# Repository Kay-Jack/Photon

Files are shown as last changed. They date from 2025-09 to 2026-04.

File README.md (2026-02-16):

# Photon

## Description
The goal of this project was to create a simple but powerful bike LED light using my remaining 18650 batteries. This is not a weak light, it delivers strong output and can be made even more powerful by swapping two resistors (one per LED) on the current contorl ICs.

A major motivation for this project was to lower the cost of bike lights, as high-quality options are often overpriced for what they offer. I also aimed to reduce labor and assembly costs, since most units would be hand-soldered. This was done by minimizing the number of unique components on the board.

The repository includes the full schematic, PCB layout, manufacturing files, and firmware for the Photon V5 revision, currently working on V6.

## Complete
- Schematic
- Board Design 
- Testing and Validation

## WIP
- Enclosure 
- New STM32 firmware 

## Features
- **Power-Efficient Design**: Utilizes a buck converter and low-power STM32
- **Compact Size**: the board compact roughly the same size as an 18650. 
- **LED Illumination**: 3W High-brightness LEDs with current control ICs.
- **Integrated Battery Charging**: A TP4056 is used for battery charging with a bidirectional side mounted LED for indication
- **Battery Protections**: Undervoltage, overvoltage and short protection is included on the board
- **Charge Detection**: The board will automatically shut off the power to the system if it detects that the board has been plugged in for charging. 
- **Debug Header**: The board uses staggered 2.54 mm header pins that create a spring effect, allowing solderless use similar to a debug header.

## Images
### PCB Front View
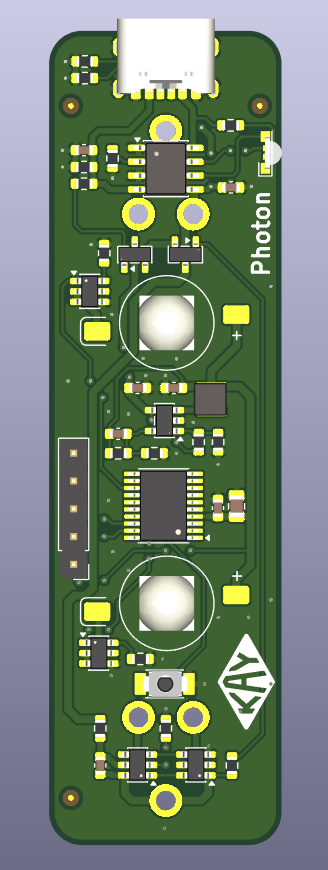
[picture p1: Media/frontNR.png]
PCB Front


### PCB Back View
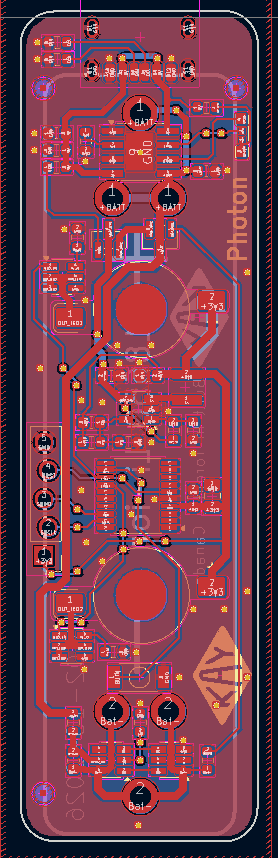
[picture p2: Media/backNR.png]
PCB Back


### Schematic 
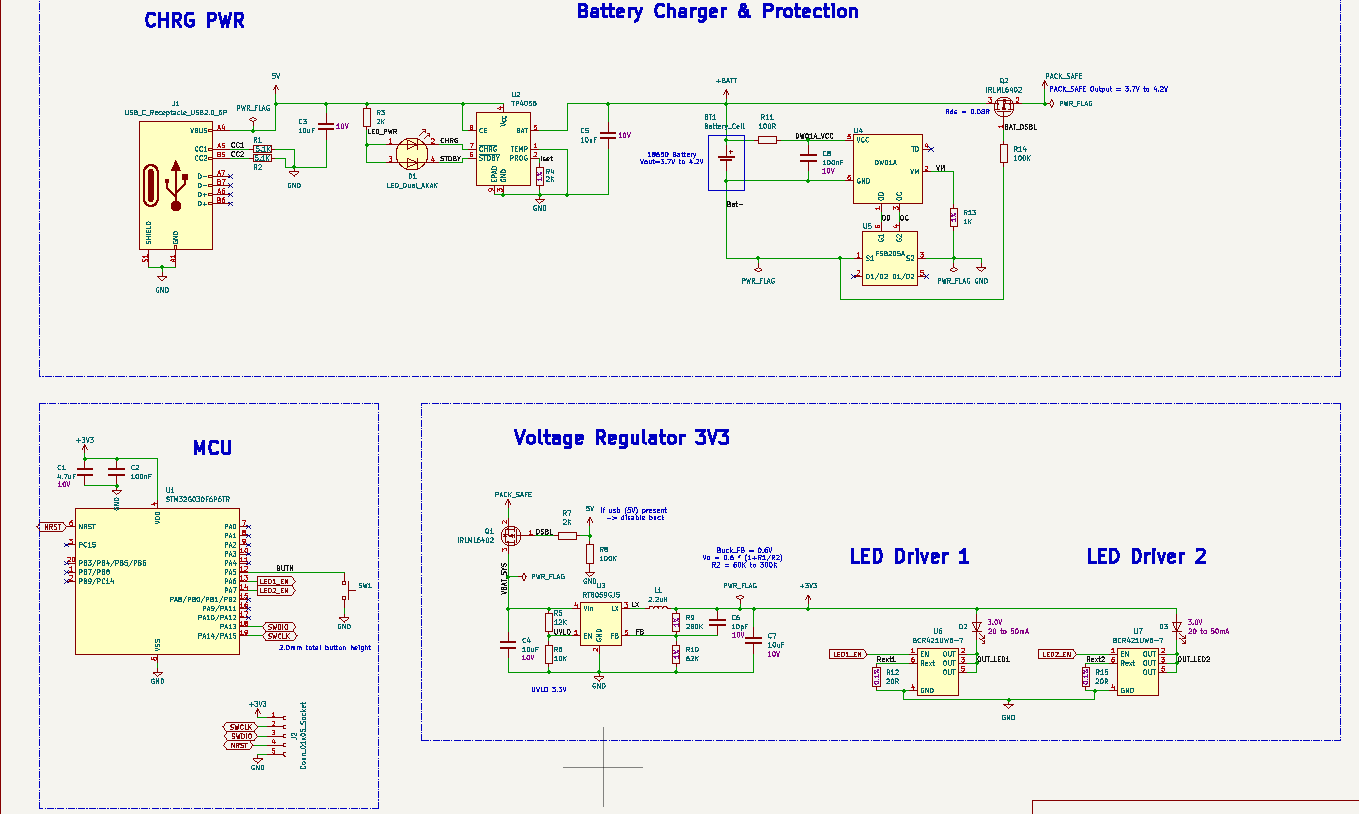
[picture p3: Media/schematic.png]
Schematic


## Version
This is version V6 of the Photon project.

## Repository
Hosted on GitHub: [AirMatress/Photon](https://github.com/AirMatress/Photon)

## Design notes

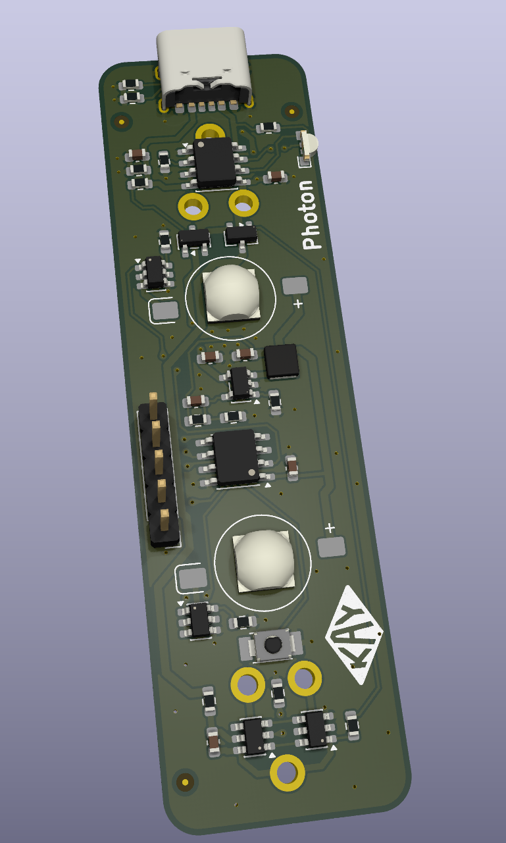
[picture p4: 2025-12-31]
Media/front.png

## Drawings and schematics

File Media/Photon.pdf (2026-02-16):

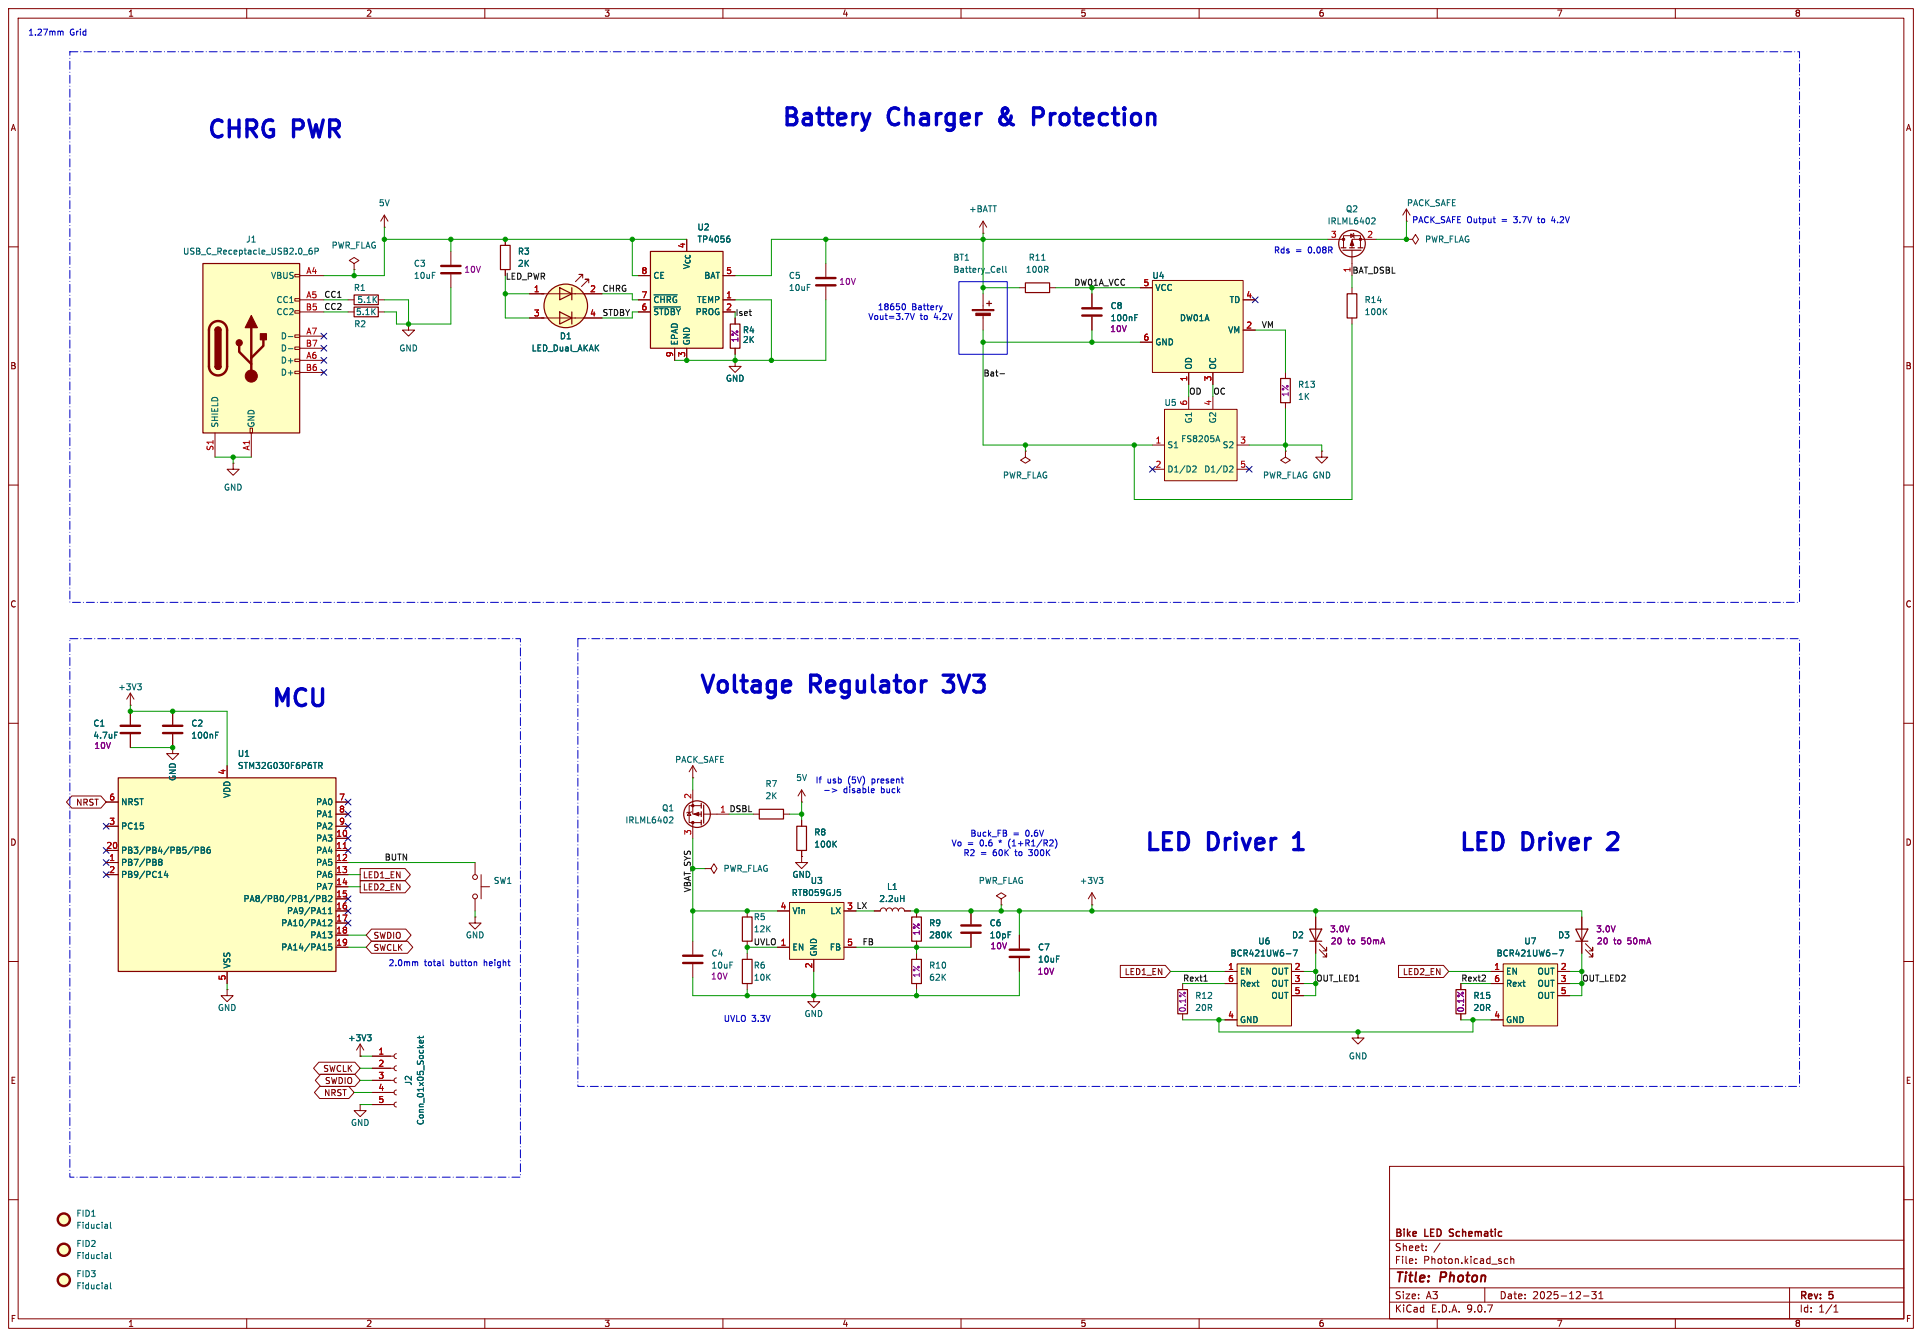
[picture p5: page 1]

Battery Charger & Protection
PACK_SAFE Output = 3.7V to 4.2V LED Driver 2

Vo = 0.6 * (1+R1/R2) R2 = 60K to 300K Voltage Regulator 3V3

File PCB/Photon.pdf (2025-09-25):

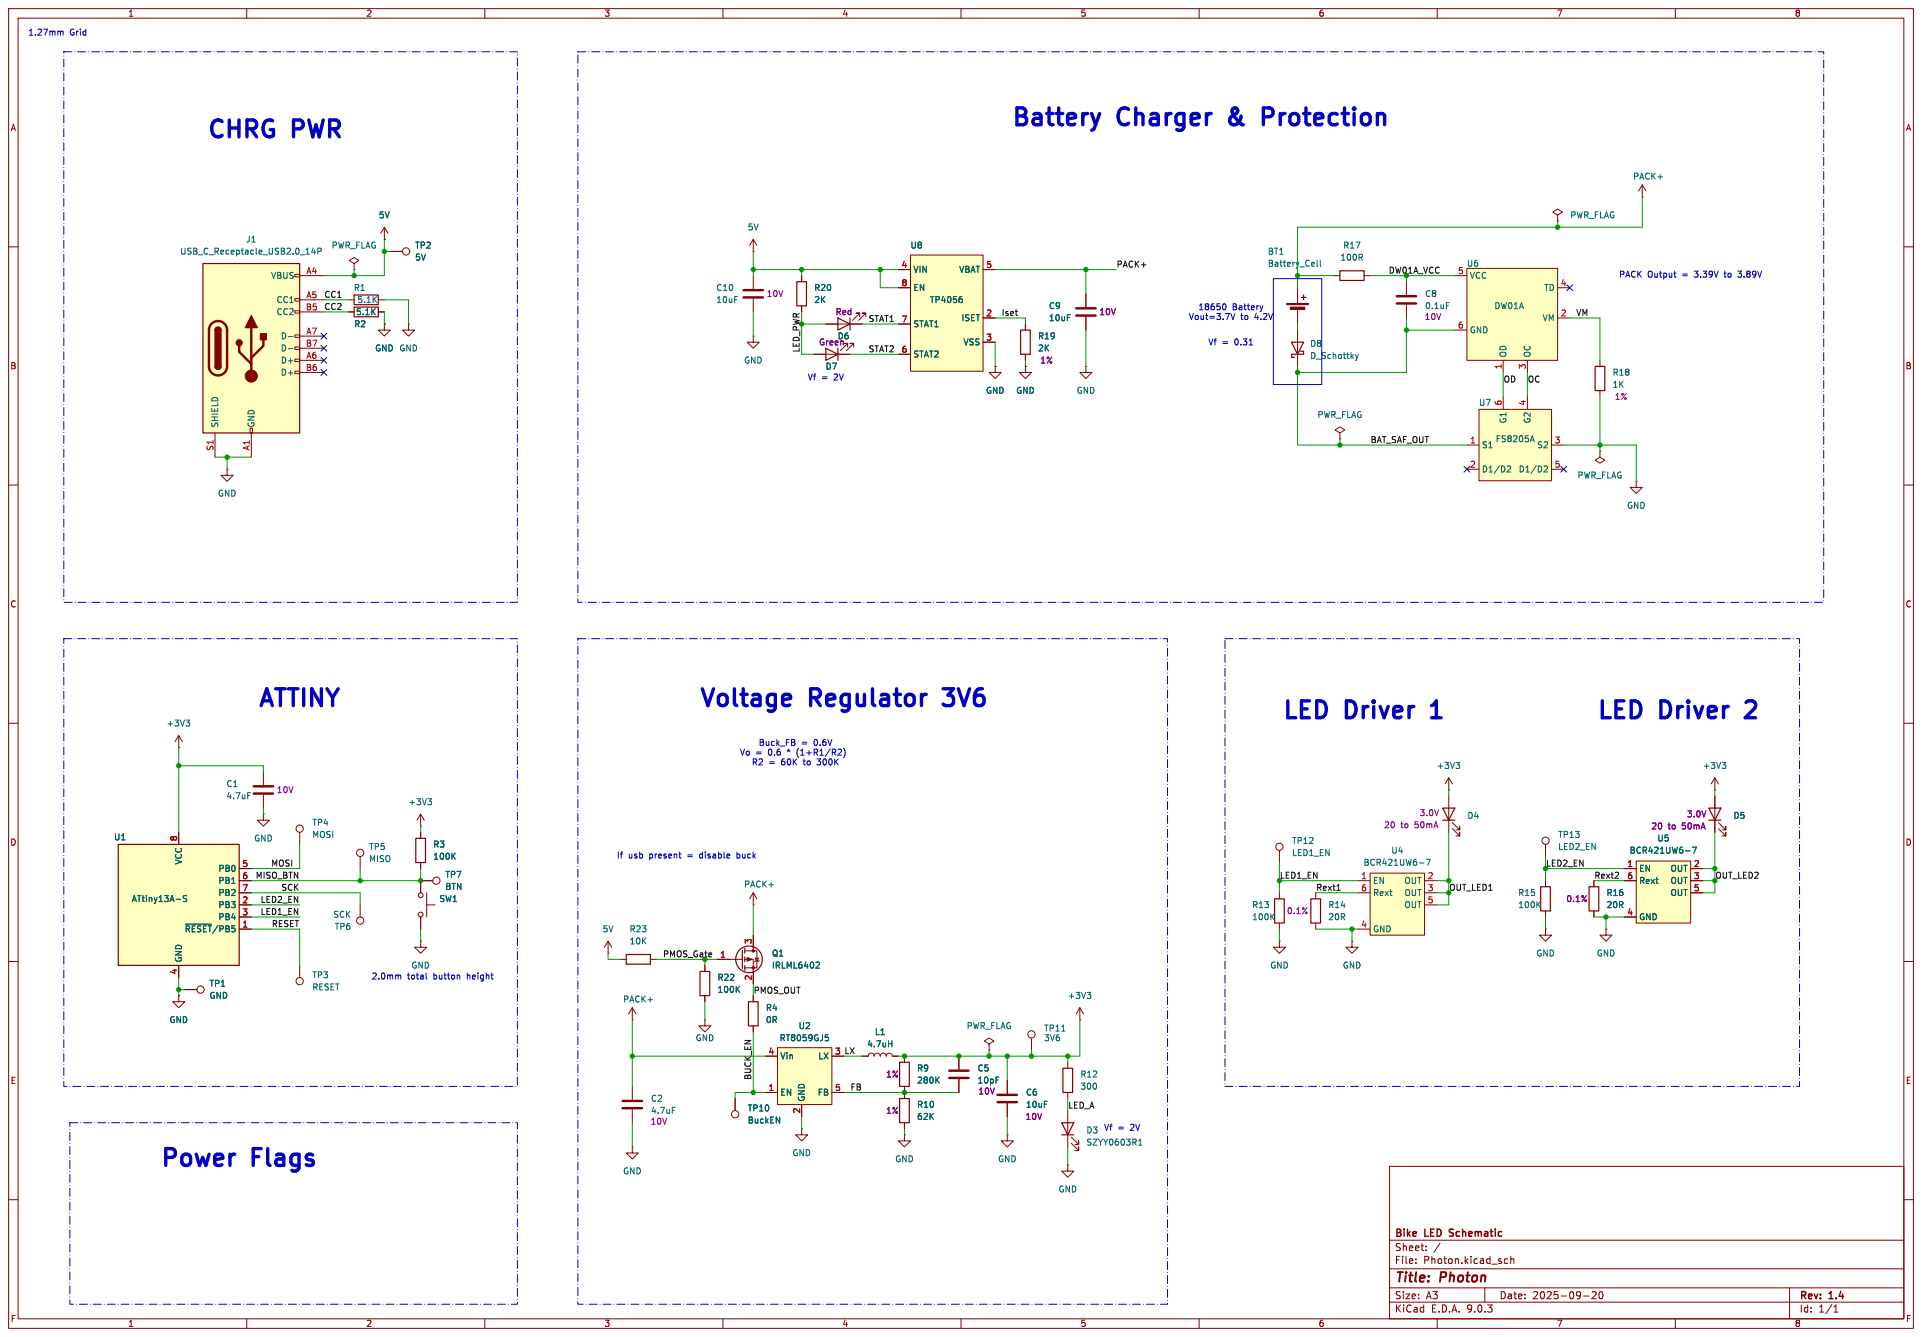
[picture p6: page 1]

If usb present = disable buck

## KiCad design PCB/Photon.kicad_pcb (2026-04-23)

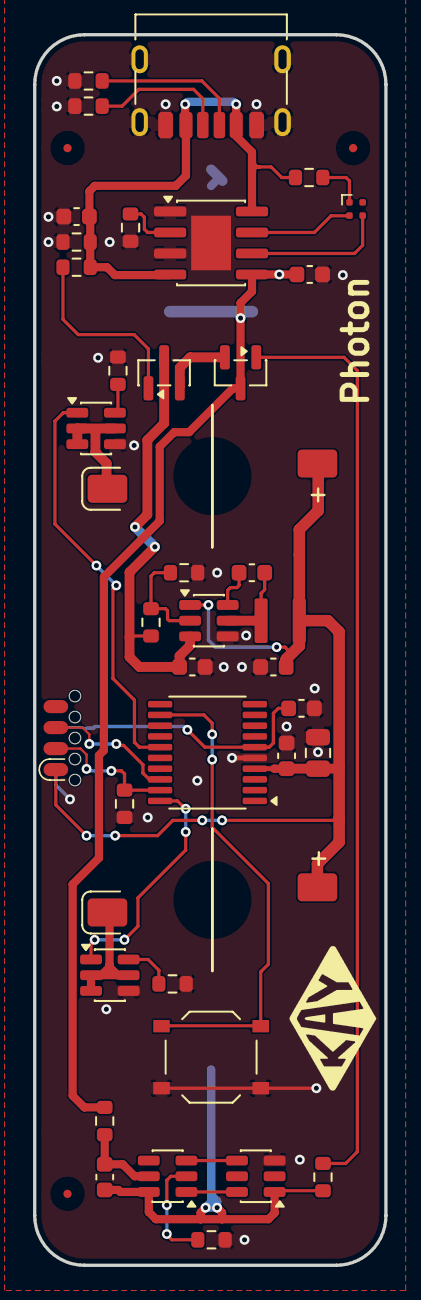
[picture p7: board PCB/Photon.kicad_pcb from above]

Board: 2 copper layers, 21.2 x 74.4 mm, 43 parts (1 on the bottom side), 32 nets.

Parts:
BT1: Battery_Cell; 18650 Tin Strips
C1: 4.7uF; C_0805_2012Metric
C2, C6, C8, C10: 100nF; C_0603_1608Metric
C3, C4, C5: 10uF; C_0603_1608Metric
C9: 22uF; C_0603_1608Metric
D1: XL-1010RGB-YG; LED_Wurth_150044M155260
D2, D3: LED; 3W LED 9mm
FID1, FID2, FID3: Fiducial; Fiducial_0.5mm_Mask1.5mm
J1: USB_C_Receptacle_USB2.0_6P; USB_C_Receptacle_HRO_TYPE-C-31-M-17
J2: SOIC 8 Debug Clip; SOIC_clipProgSmall
L1: 4.7uH; SMD 3x3mm Power Inductor
Q1, Q2: IRLML6402; SOT-23
R1, R2: 5.1K; R_0603_1608Metric
R3, R4, R7: 2K; R_0603_1608Metric
R5: 180K; R_0603_1608Metric
R6, R8, R14: 100K; R_0603_1608Metric
R9: 10K; R_0603_1608Metric
R11: 100R; R_0603_1608Metric
R12, R15: 20R; R_0603_1608Metric
R13: 1K; R_0603_1608Metric
SW1: TS-1088-AR02016; SW_Push_1P1T_XKB_TS-1187A
U1: STM32G030F6P6TR; TSSOP-20_4.4x6.5mm_P0.65mm
U2: TP4056; SOIC-8-1EP_3.9x4.9mm_P1.27mm_EP2.41x3.3mm
U3: AP63203WU; TSOT-23-6
U4: DW01A; SOT-23-6
U5: FS8205A; SOT-23-6
U6, U7: BCR421UW6-7; SOT-23-6

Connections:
5V: C3.2, J1.A9 (VBUS), J1.B9 (VBUS), R3.1, R7.2, R8.1, U2.4 (V_{CC}), U2.8 (CE)
+3V3: C1.2, C2.1, C9.2, D2.2 (A), D3.2 (A), J2.1, L1.2, U1.4 (VDD), U3.1 (FB)
+BATT: BT1.1 (+), C5.2, Q2.3 (D), R11.1, U2.5 (BAT)
/BAT_DSBL: Q2.1 (G), R14.2
/BST: C6.2, U3.6 (BST)
/BUTN: SW1.1, U1.12 (PA5)
/Bat-: BT1.2 (-), C8.1, R14.1, U4.6 (GND), U5.1 (S1)
/CC1: J1.A5 (CC1), R1.1
/CC2: J1.B5 (CC2), R2.1
/CHRG: D1.3 (RK), U2.7 (~CHRG)
/DSBL: Q1.1 (G), R7.1
/DW01A_VCC: C8.2, R11.2, U4.5 (VCC)
/Iset: R4.1, U2.2 (PROG)
/LED_PWR: D1.1 (A), R3.2
/OC: U4.3 (OC), U5.4 (G2)
/OD: U4.1 (OD), U5.6 (G1)
/OUT_LED1: D2.1 (K), U6.2 (OUT), U6.3 (OUT), U6.5 (OUT)
/OUT_LED2: D3.1 (K), U7.2 (OUT), U7.3 (OUT), U7.5 (OUT)
/Rext1: R12.1, U6.6 (Rext)
/Rext2: R15.1, U7.6 (Rext)
/STDBY: D1.4 (GK), U2.6 (~STDBY)
/SW: C6.1, L1.1, U3.5 (SW)
/UVLO: R5.2, R6.1, U3.2 (EN)
/VBAT_SYS: C4.2, Q1.3 (D), R5.1, U3.3 (IN)
/VM: R13.2, U4.2 (VM)
GND: C1.1, C2.2, C3.1, C4.1, C5.1, C9.1, C10.1, J1.A12 (GND), J1.B12 (GND), J1.S1 (SHIELD), J2.8, R1.2, R2.2, R4.2, R6.2, R8.2, R9.2, R12.2, R13.1, R15.2, SW1.2, U1.5 (VSS), U2.1 (TEMP), U2.3 (GND), U2.9 (EPAD), U3.4 (GND), U5.3 (S2), U6.4 (GND), U7.4 (GND)
LED1_EN: U1.15 (PA8/PB0/PB1/PB2), U6.1 (EN)
LED2_EN: U1.20 (PB3/PB4/PB5/PB6), U7.1 (EN)
NRST: C10.2, J2.6, U1.6 (NRST)
PACK_SAFE: Q1.2 (S), Q2.2 (S)
SWCLK: J2.2, R9.1, U1.19 (PA14/PA15)
SWDIO: J2.3, U1.18 (PA13)

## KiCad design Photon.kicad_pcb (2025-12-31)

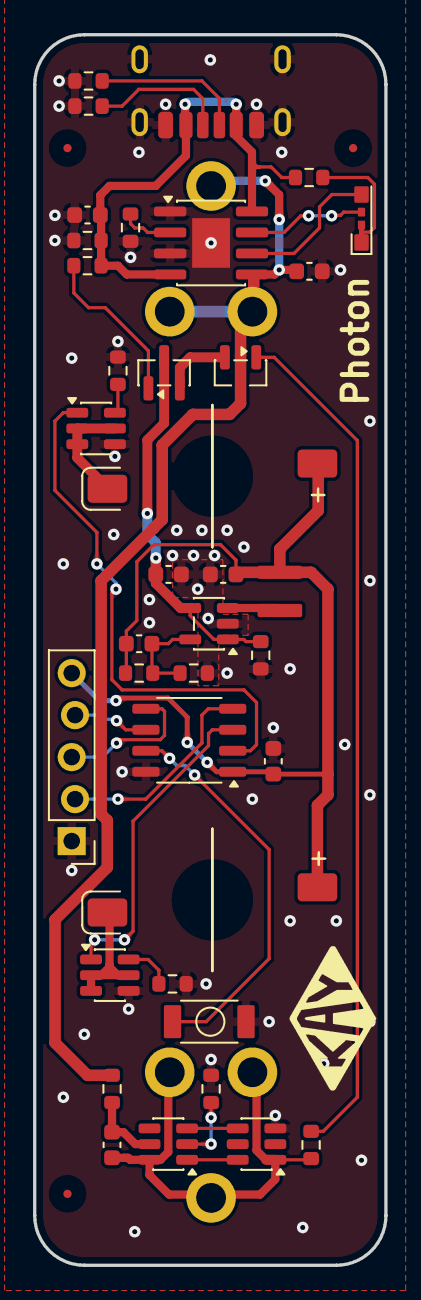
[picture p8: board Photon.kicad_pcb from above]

Board: 2 copper layers, 21.2 x 74.4 mm, 41 parts (1 on the bottom side), 31 nets.

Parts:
BT1: Battery_Cell; Spring Battery TH
C1, C7: 100nF; C_0603_1608Metric
C2, C3, C5, C6: 10uF; C_0603_1608Metric
C4: 10pF; C_0603_1608Metric
D1: LED_Dual_AKAK; 3.9mm Bi directional side mount LED
D2, D3: LED; 3W LED 9mm
FID1, FID2, FID3: Fiducial; Fiducial_0.5mm_Mask1.5mm
J1: USB_C_Receptacle_USB2.0_14P; USB_C_Receptacle_HRO_TYPE-C-31-M-17
J2: Conn_01x05_Socket; PinHeader_1x05_P2.54mm_Vertical
L1: 2.2uH; SMD 3x3mm Power Inductor
Q1, Q2: IRLML6402; SOT-23
R1, R2: 5.1K; R_0603_1608Metric
R4, R7, R10: 2K; R_0603_1608Metric
R5, R6, R19: 100K; R_0603_1608Metric
R8: 280K; R_0603_1608Metric
R9: 62K; R_0603_1608Metric
R13, R16: 20R; R_0603_1608Metric
R14: 100R; R_0603_1608Metric
R17: 1K; R_0603_1608Metric
SW1: TS-1088-AR02016; 5mm Push Button
U1: PY32F002AL15S6TU; SOP-8_3.9x4.9mm_P1.27mm
U2: TP4056; SOIC-8-1EP_3.9x4.9mm_P1.27mm_EP2.29x3mm
U3: RT8059GJ5; SOT-23-5
U4, U7: BCR421UW6-7; SOT-23-6
U5: DW01A; SOT-23-6
U6: FS8205A; SOT-23-6

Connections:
5V: C3.2, J1.A9 (VBUS), J1.B9 (VBUS), R4.2, R5.1, R7.1, U2.4 (V_{CC}), U2.8 (CE)
+3V3: C1.2, C4.2, C5.2, D2.2 (A), D3.2 (A), J2.5, L1.2, R8.1, U1.1 (VDD)
+BATT: BT1.1 (+), C6.2, Q2.3 (D), R14.1, U2.5 (BAT)
/BAT_DSBL: Q2.1 (G), R19.2
/BTN: SW1.1, U1.7 (PA1)
/Bat-: BT1.2 (-), C7.1, R19.1, U5.6 (GND), U6.1 (S1)
/CC1: J1.A5 (CC1), R1.1
/CC2: J1.B5 (CC2), R2.1
/CHRG: D1.2 (K1), U2.7 (~CHRG)
/DSBL: Q1.1 (G), R4.1
/DW01A_VCC: C7.2, R14.2, U5.5 (VCC)
/FB: C4.1, R8.2, R9.1, U3.5 (FB)
/Iset: R10.1, U2.2 (PROG)
/LED1_EN: U1.2 (PA4/PA10), U4.1 (EN)
/LED2_EN: U1.3 (PA3), U7.1 (EN)
/LED_PWR: D1.1 (A1), D1.3 (A2), R7.2
/LX: L1.1, U3.3 (LX)
/NRST: J2.4, U1.6 (PA2/PF2/NRST)
/OC: U5.3 (OC), U6.4 (G2)
/OD: U5.1 (OD), U6.6 (G1)
/OUT_LED1: D2.1 (K), U4.2 (OUT), U4.3 (OUT), U4.5 (OUT)
/OUT_LED2: D3.1 (K), U7.2 (OUT), U7.3 (OUT), U7.5 (OUT)
/Rext1: R13.1, U4.6 (Rext)
/Rext2: R16.1, U7.6 (Rext)
/STDBY: D1.4 (K2), U2.6 (~STDBY)
/SWC: J2.2, U1.4 (PA14/PB3/SWC)
/SWD: J2.3, U1.5 (PA13/SWD)
/VBAT_SYS: C2.2, Q1.3 (D), R6.1, U3.1 (EN), U3.4 (Vin)
/VM: R17.2, U5.2 (VM)
GND: C1.1, C2.1, C3.1, C5.1, C6.1, J1.A12 (GND), J1.B12 (GND), J1.S1 (SHIELD), J2.1, R1.2, R2.2, R5.2, R6.2, R9.2, R10.2, R13.2, R16.2, R17.1, SW1.2, U1.8 (GND), U2.1 (TEMP), U2.3 (GND), U2.9 (EPAD), U3.2 (GND), U4.4 (GND), U6.3 (S2), U7.4 (GND)
PACK_SAFE: Q1.2 (S), Q2.2 (S)

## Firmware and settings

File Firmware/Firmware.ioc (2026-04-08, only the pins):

Mcu.UserName=STM32G030F6Px
PA13.Signal=SYS_SWDIO
PA14-BOOT0.Signal=SYS_SWCLK
PA5.GPIO_Label=BUTTON
PA5.Signal=GPIO_Input
PA8.GPIO_Label=LED1_EN
PA8.Signal=S_TIM1_CH1
PB3.GPIO_Label=LED2_EN
PB3.Signal=S_TIM1_CH2

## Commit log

2025-08-03 made new pcb. and updated schematic
    [Photon.kicad_pcb, Photon.kicad_sch]
2025-08-08 Cleaned up schematic and PCB
    [Photon-+BATT.gbr, Photon-3_6V.gbr, Photon-B_Mask.gbr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]
2025-09-06 New Battery IC
    [Photon.kicad_sch]
2025-09-08 added new ic and started layout
    [Photon.kicad_pcb, Photon.kicad_sch]
2025-09-11 Added TP4056 back
    [Photon.kicad_pcb, Photon.kicad_sch]
2025-09-15 Aadjusted placement of schematic
    [Photon.kicad_sch]
2025-09-22 added usb detection circuit and battery protection
    [Photon.kicad_pcb, Photon.kicad_sch]
2025-09-25 PCB layout complete
    [Photon.kicad_pcb, Photon.kicad_sch]
2025-09-26 added fiducials and gerbers. - Ordered
    [Photon-+BATT.gbr, Photon-3_3V.gbr, Photon-3_6V.gbr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]
2025-09-28 updated gerbers
    [Photon-3_3V.gbr, Photon-B_CU.gbr, Photon-B_Mask.gbr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]
2025-10-02 finished v3 of pcb
    [Photon-B_CU.gbr, Photon-B_Mask.gbr, Photon-B_Silkscreen.gbr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]
2025-11-05 Cleaned up PCB
    [Photon.kicad_pcb, Photon.kicad_sch]
2025-11-10 made RT805 smaller footprint, moved few parts around and center tp4056 more over battery through holes
    [Photon.kicad_pcb, Photon.kicad_sch]
2025-11-15 small changed and exported .step
    [Photon.kicad_pcb, Photon.step]
2025-11-16 gerbers and a few components moved
    [Photon-3_3V.gbr, Photon-B_CU.gbr, Photon-B_Mask.gbr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]
2025-12-22 removing un needed parts
    - pulldowns on LEDs
    - pulldown on Buck
    - cleaned up schematic
    [Photon.kicad_sch]
2025-12-26 Swapped out MCU
    - not completed (WIP)
    [Photon.kicad_pcb, Photon.kicad_sch]
2025-12-27 Updated schem and PCB. updated footprints
    [Photon.kicad_pcb, Photon.kicad_sch]
2025-12-29 added stitching vias and bi direction led for charging
    [Photon.kicad_pcb, Photon.kicad_sch]
2025-12-31 Edged clearance resolved and programming connector modified
    [Photon.kicad_pcb]
2025-12-31 improvements
    - added pull down to buck (previously there and was removed)
    - Simplified PCB by rotating components to reduce vias
    - updated value fields and annotated schematic
    [Photon.kicad_pcb, Photon.kicad_sch]
2025-12-31 small change
    Moved Q1 down .3mm
    [Photon.kicad_pcb]
2025-12-31 added CAD files and created gerbers
    [Photon-B_CU.gbr, Photon-B_Mask.gbr, Photon-B_Silkscreen.gbr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]
2025-12-31 Gerbers updated again
    [Photon-B_CU.gbr, Photon-B_Mask.gbr, Photon-B_Silkscreen.gbr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]
2025-12-31 added .gitignore and removed backup files
    [Photon.kicad_pcb, Photon.kicad_sch]
2026-02-16 Squashed commit of the following:
    commit 040f56c92c5fbfa60c6357d084ca9e817f85bd74
    Author: AirMatress <134566567+Kay-Jack@users.noreply.github.com>
    Date: Sun Feb 15 22:31:25 2026 -0500
    changed folder structure and added new photos
    commit a5de8e0470fd1fbaa1884b4c13b8efd9701bd3f9
    Author: AirMatress <134566567+Kay-Jack@users.noreply.github.com>
    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
    [Photon Only Board.step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]
2026-02-16 caps too close, resolved and updated gerbers
    [Photon-B_CU.gbr, Photon-B_Mask.gbr, Photon-B_Paste.gbr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]
2026-02-16 updated pcb
    [Photon.kicad_pcb]
2026-04-08 Schematic, Board and Firmware changes
    Moved pins for LEDs onto timer channel capable pins to allow for future implementation if desired
    Added 100nF cap to NRST pin
    Changed programming footprint to use soic8 programmers found on Github
    Changed buck to diodes fixed version (AP63203WU) for fewer components
    Created Gerbers
    Updated .ioc for pinout using timer channels and naming pins to match
    Added footprint for debugger
    [Photon-B_CU.gbr, Photon-B_Mask.gbr, Photon-B_Paste.gbr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]
2026-04-08 updated silkscreen to match gerbers
    [Photon.kicad_pcb]
2026-04-08 added new inductor links
    [Photon.kicad_sch]
2026-04-23 Component changes for better button and LED
    [Photon.kicad_pcb, Photon.kicad_sch]
